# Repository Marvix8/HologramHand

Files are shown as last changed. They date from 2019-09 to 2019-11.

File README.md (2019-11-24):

# Sistemas Operativos Avanzados

## Grupo: &nbsp;X1
- Amengual, Miguel Angel &nbsp;&nbsp;&nbsp;&nbsp;&nbsp; 35991055
- Castagna, Cristian Damian &nbsp;&nbsp;&nbsp;&nbsp;&nbsp; 37398696
- Krause, Ezequiel Otto &nbsp;&nbsp;&nbsp;&nbsp;&nbsp; 39758862
- Scarpello, Franco Dario &nbsp;&nbsp;&nbsp;&nbsp;&nbsp; 37842567

## Proyecto: &nbsp;HologramHand
El fin es crear una experiencia salida de pelicula, al poder **controlar hologramas con gestos de la mano.**

Para poder vivir la experiencia se necesita del guante que estamos desarrollando, siendo este un periférico (mouse, joystick) para celulares, un celular con Android y una sencilla pirámide de acrílico.

Pasos: 
-colocar guante y conectar al celular
-abrir aplicación
-colocar piramide de forma invertida sobre la pantalla con el dispositivo reposado.

**Se recomienda poca luz ambiente*

Y listo, ahora tendrás que comenzar a realizar gesto intuitivos con la mano para por ejmplo pasar de holograma a holograma, achicarlos, agrandarlos y darle a "play" en caso de tener movimiento.

## Descripción detallada del sistema y diseño incremental (Embebido)

### Arduino Uno
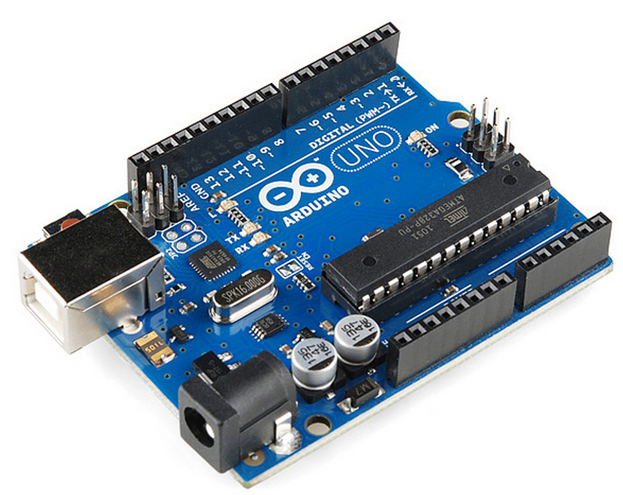
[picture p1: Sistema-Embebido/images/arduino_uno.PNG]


El hardware de Arduino consiste en una placa con un microcontrolador generalmente Atmel con puertos de comunicación y puertos de entrada/salida.

Arduino Uno es una placa electrónica basada en el microcontrolador ATMega 328. Cuenta con 14 entradas/salidas digitales, de las cuales 6 se pueden utilizar como salidas PWM(modulación por ancho de pulsos) y otras 6 son entradas analógicas.

### Bluetooth HC-06
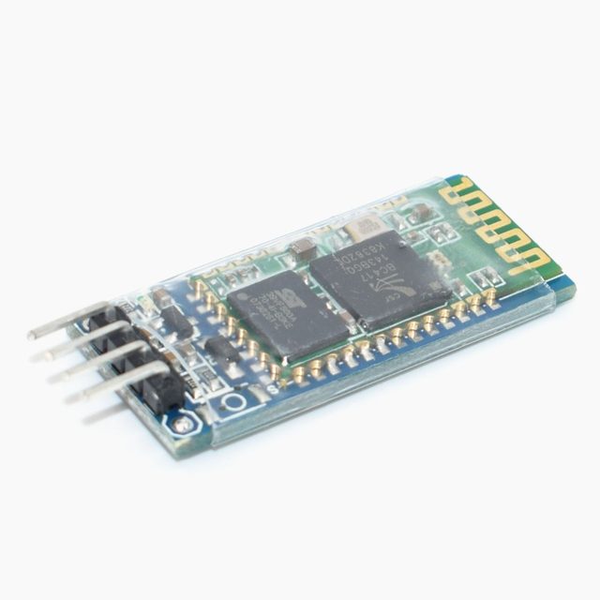
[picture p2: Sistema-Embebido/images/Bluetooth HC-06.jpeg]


El módulo de bluetooth HC-06 es un módulo esclavo, quiere decir que puede recibir conexiones desde un celular, PC, Tablet, pero no es capaz de generar conexiones hacia otros dispositivos bluetooth.

Tiene un modo de comandos AT que debe activarse. Una vez que estamos en el modo de comandos AT, podemos configurar el módulo bluetooth y cambiar parámetros como el nombre del dispositivo, contraseña, entre otras. 

Las conexiones para realizar con Arduino son bastante sencillas. Solamente requerimos colocar como mínimo la alimentación y conectar los pines de transmisión y recepción serial (TX y RX). Hay que recordar que en este caso los pines se deben conectar TX Bluetooth -> TX de Arduino y RX Bluetooth -> RX de Arduino.

### MPU-9250 (Acelerómetro).
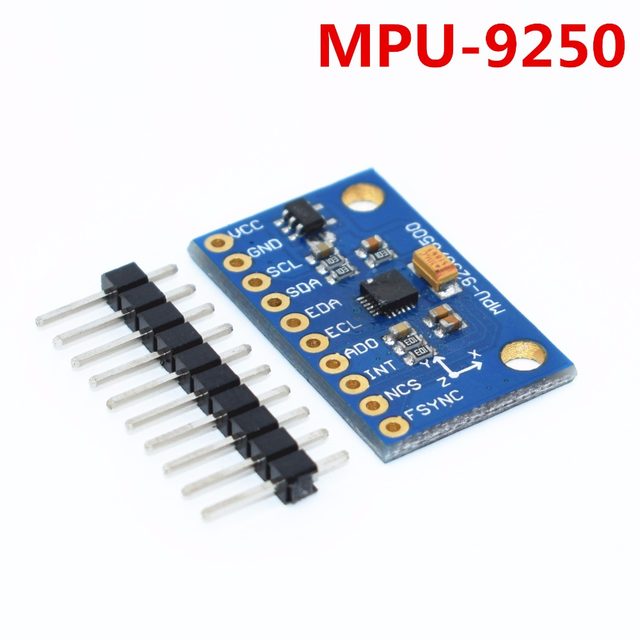
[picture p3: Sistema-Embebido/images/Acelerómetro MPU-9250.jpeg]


Este módulo está basado en el sensor MPU9250 y contiene todo lo necesario para realizar rastreo de movimiento de 9 ejes (9 DoF). Combina un giroscopio de 3 ejes, un acelerómetro de 3 ejes y un magnetómetro de 3 ejes en un mismo chip. Integra un DMP (Procesador digital de movimiento) capaz de realizar complejos algoritmos de captura de movimiento de 9 ejes.

Se comunica con microcontroladores a través de una interfaz I2C y posee una librería muy difundida para su uso inmediato. Este sensor puede entregar 9 grados de libertad e incorpora un regulador de tensión a 3.3V y resistencias pull-up para su uso directo por I2C.

Para una captura precisa de movimiento rápido y lento, posee un rango de escala programable de 250/500/1000/2000 grados/seg para el giroscopio, 2g/4g/8g/16g para el acelerómetro y ±4800µT para el magnetómetro.

### Flex
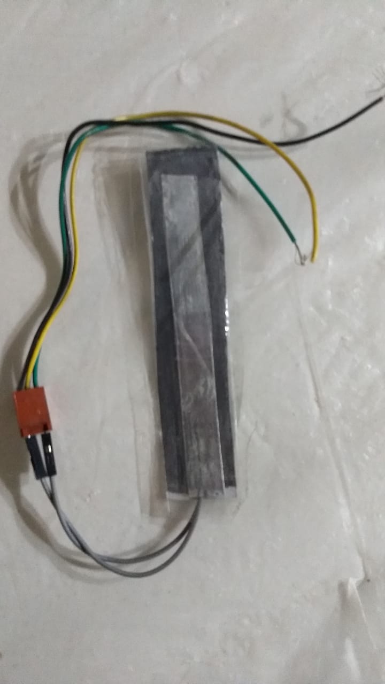
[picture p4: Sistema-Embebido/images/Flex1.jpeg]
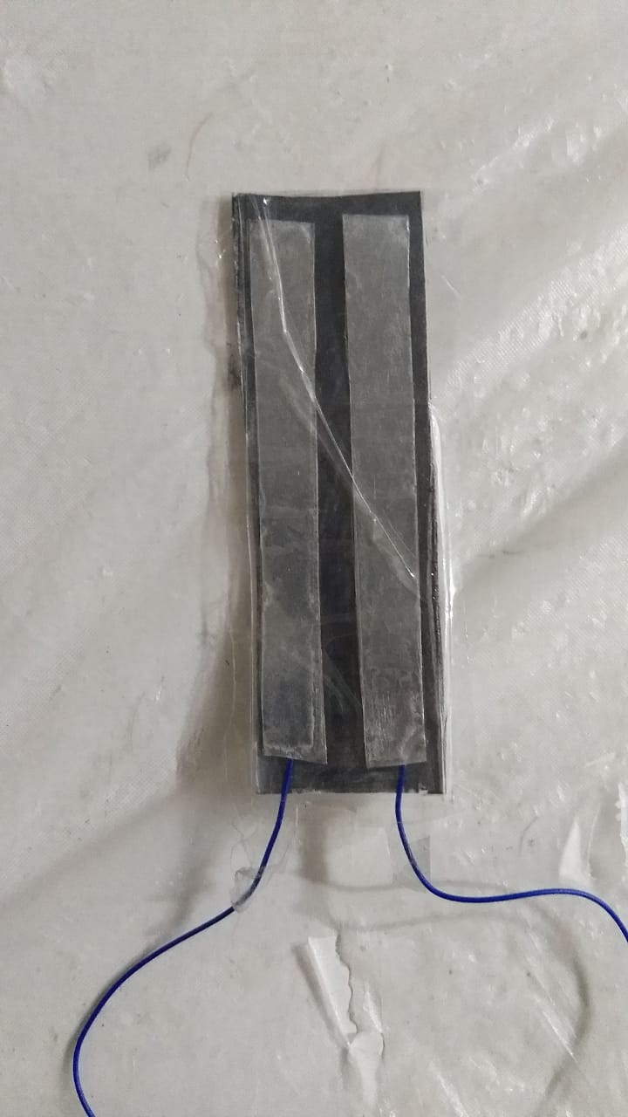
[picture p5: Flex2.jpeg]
  

Este sensor aumenta su resistencia al ser flexionado. El conector tiene dos cables para conectarse directamente al protoboard.
Las dimensiones son 10 cm. x 3 cm. aunque la parte útil que medirá la resistencia doblado es de 8 cm.

### Led Digital
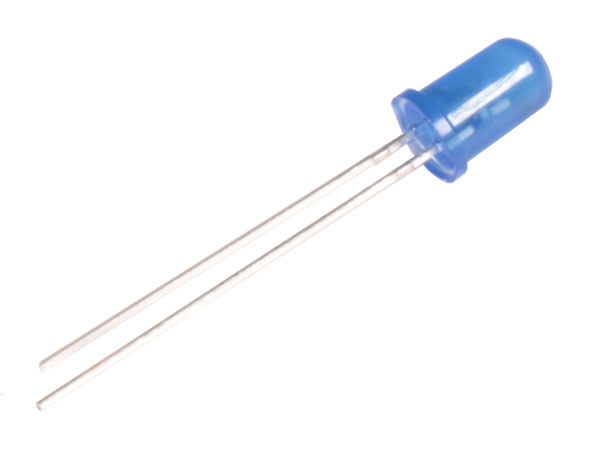
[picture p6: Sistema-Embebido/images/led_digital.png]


Los LEDs de 5mm se presentan encapsulados en una cúpula de resina de color que tiene dos patas. La pata más larga es la de polaridad negativa y se denomina ánodo, la más corta es de polaridad positiva.

-	Color: Azul (455-465nm)
-	Ángulo de apertura: 120 grados
-	Diámetro: 5mm
-	Intensidad lumínica: 4000-5000 mcd
-	Tensión de entrada: 3 V-3,2 V
-	Corriente: 20 mA

### Led Analógico RGB
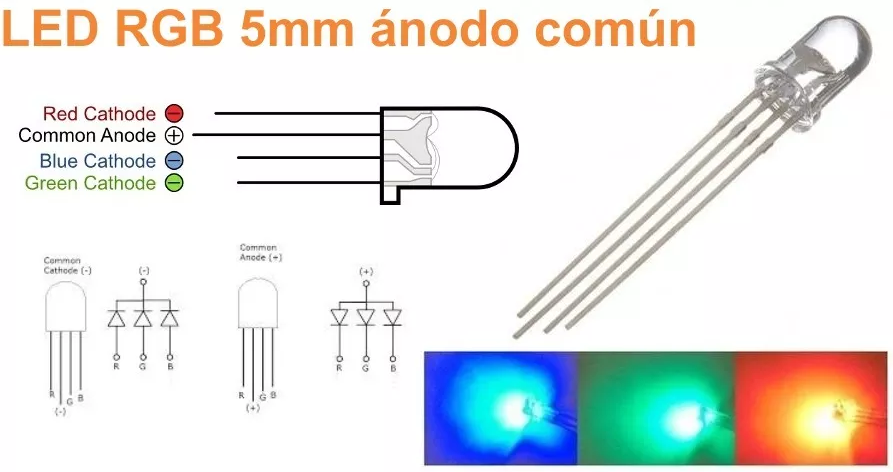
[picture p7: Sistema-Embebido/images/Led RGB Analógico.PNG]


Los LEDs de 5mm se presentan encapsulados en una cúpula de resina de color transparente que tiene cuatro patas: la más larga es de polaridad negativa y se denomina ánodo, las más cortas son de polaridad positiva y se denominan cátodo, en este caso representan el cátodo de R, G y B. Mediante estas patas se indicará la forma en la que el LED debe ser conectado al circuito.

-	Color: RGB
-	Ángulo de apertura: 30 grados
-	Diámetro: 5 mm
-	Longitud de onda: R:625 - G:525 - B:465 nM
-	Tensión de entrada: R:2,1 - G:3,1 - B:3,1 V
-	Intensidad lumínica R:2000 - G:4000 - B:2000 mcd
-	Dimerizable

### Diagrama Físico

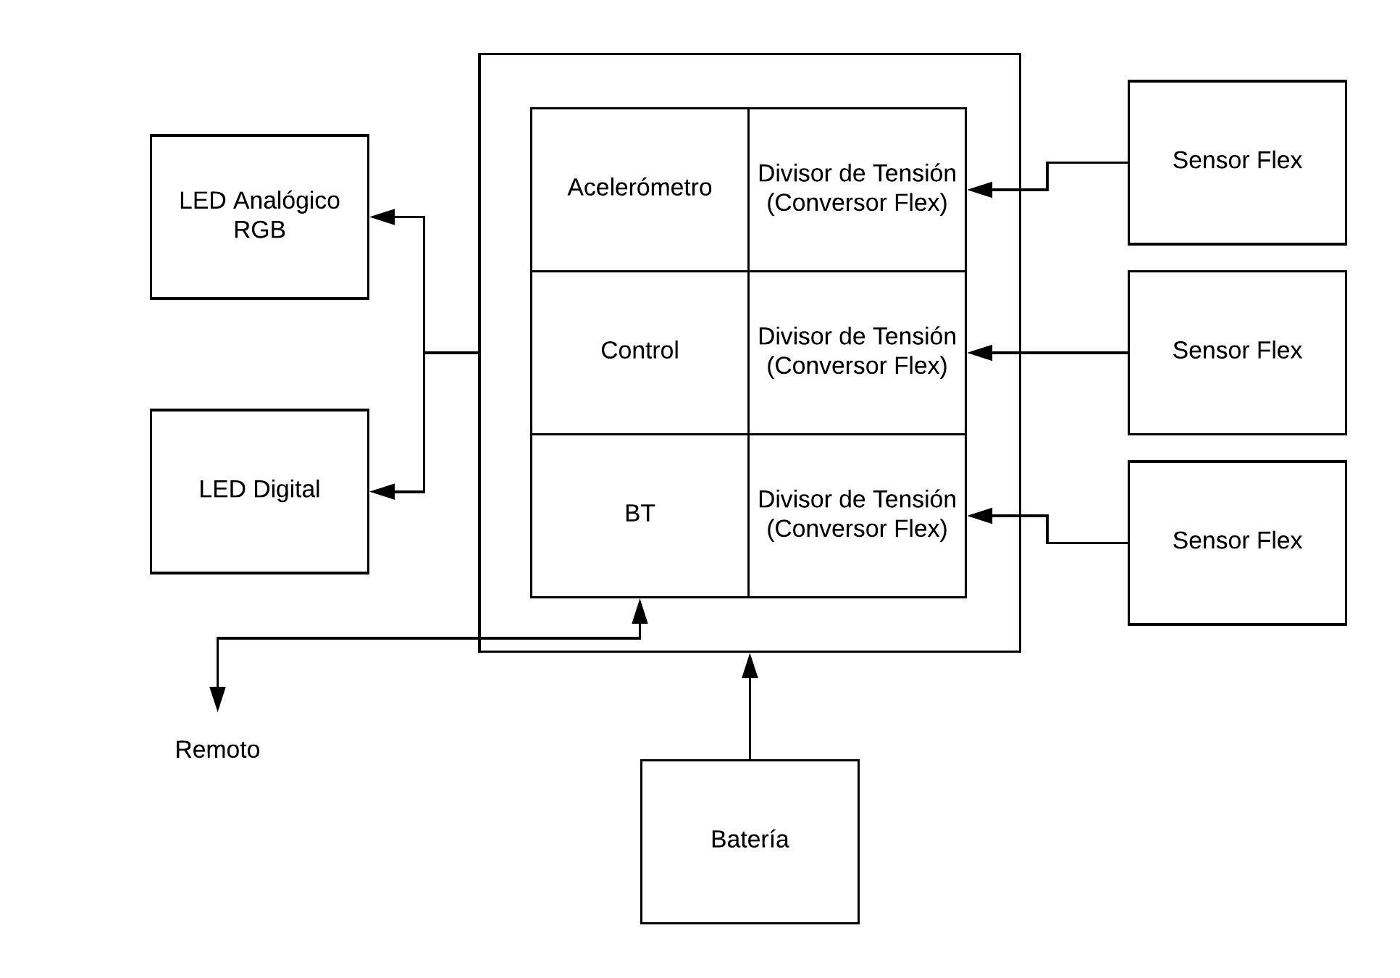
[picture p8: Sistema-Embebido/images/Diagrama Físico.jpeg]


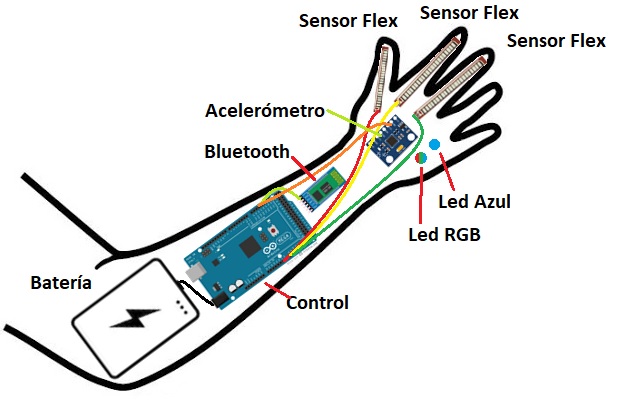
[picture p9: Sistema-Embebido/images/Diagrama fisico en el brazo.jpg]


### Diagrama Lógico

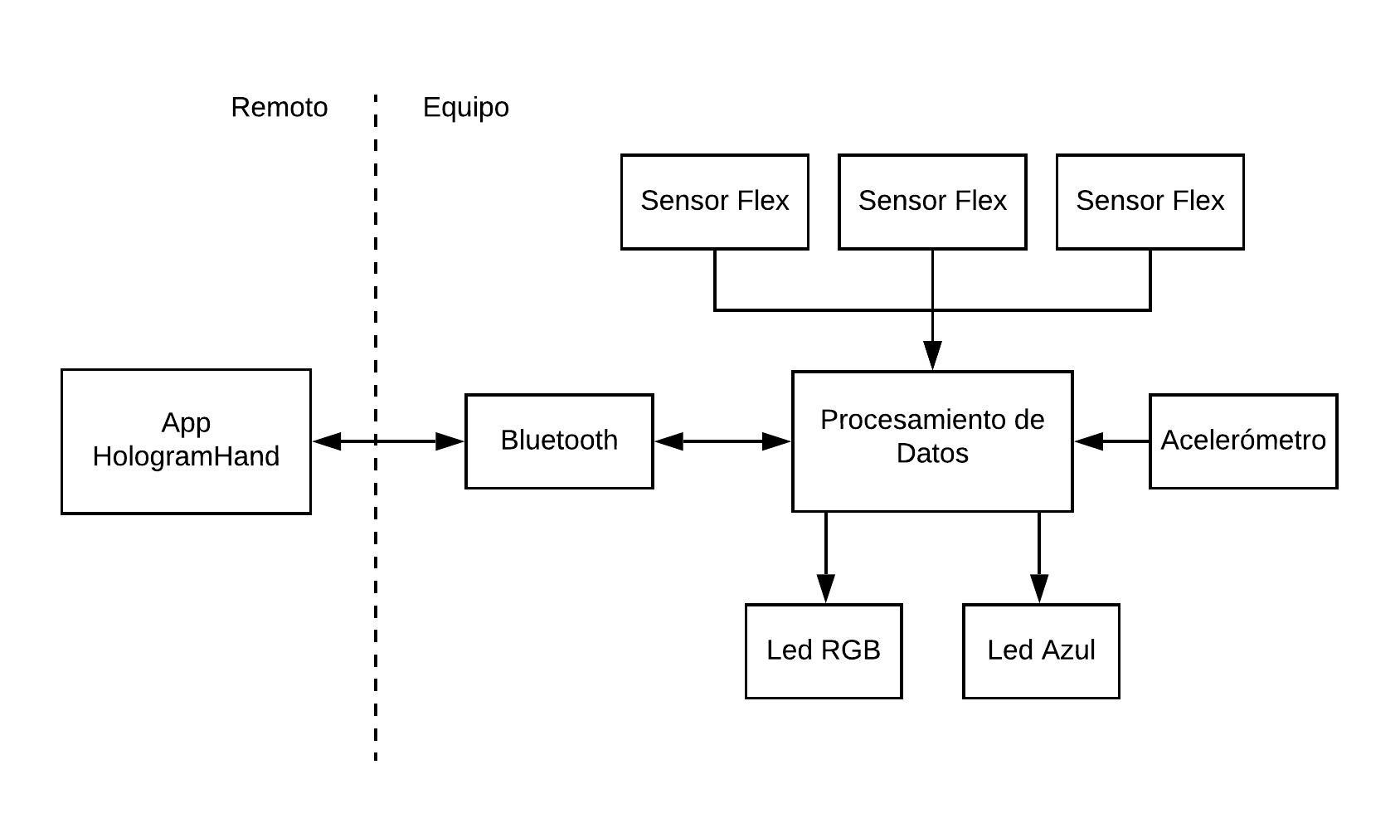
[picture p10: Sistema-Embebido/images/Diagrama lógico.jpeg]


### Diagrama Funcional

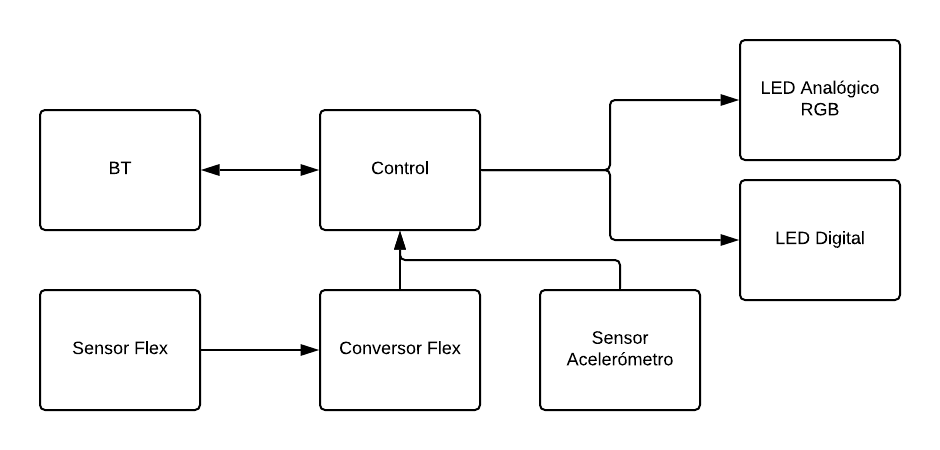
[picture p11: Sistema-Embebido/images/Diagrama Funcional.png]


### Diagrama Circuital

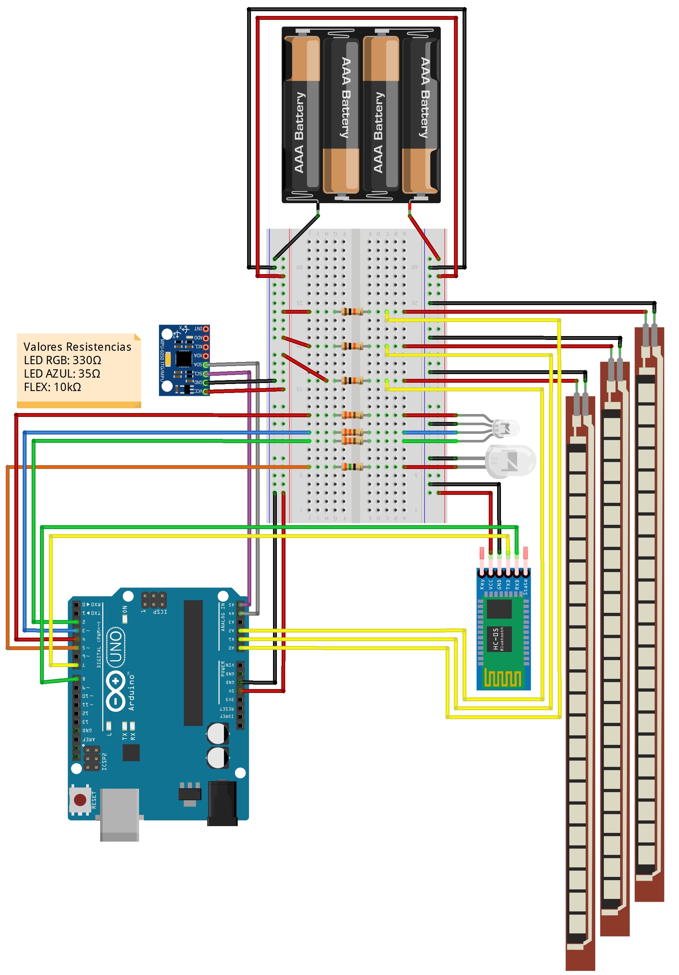
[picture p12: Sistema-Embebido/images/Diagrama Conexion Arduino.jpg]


### Diagrama de Software

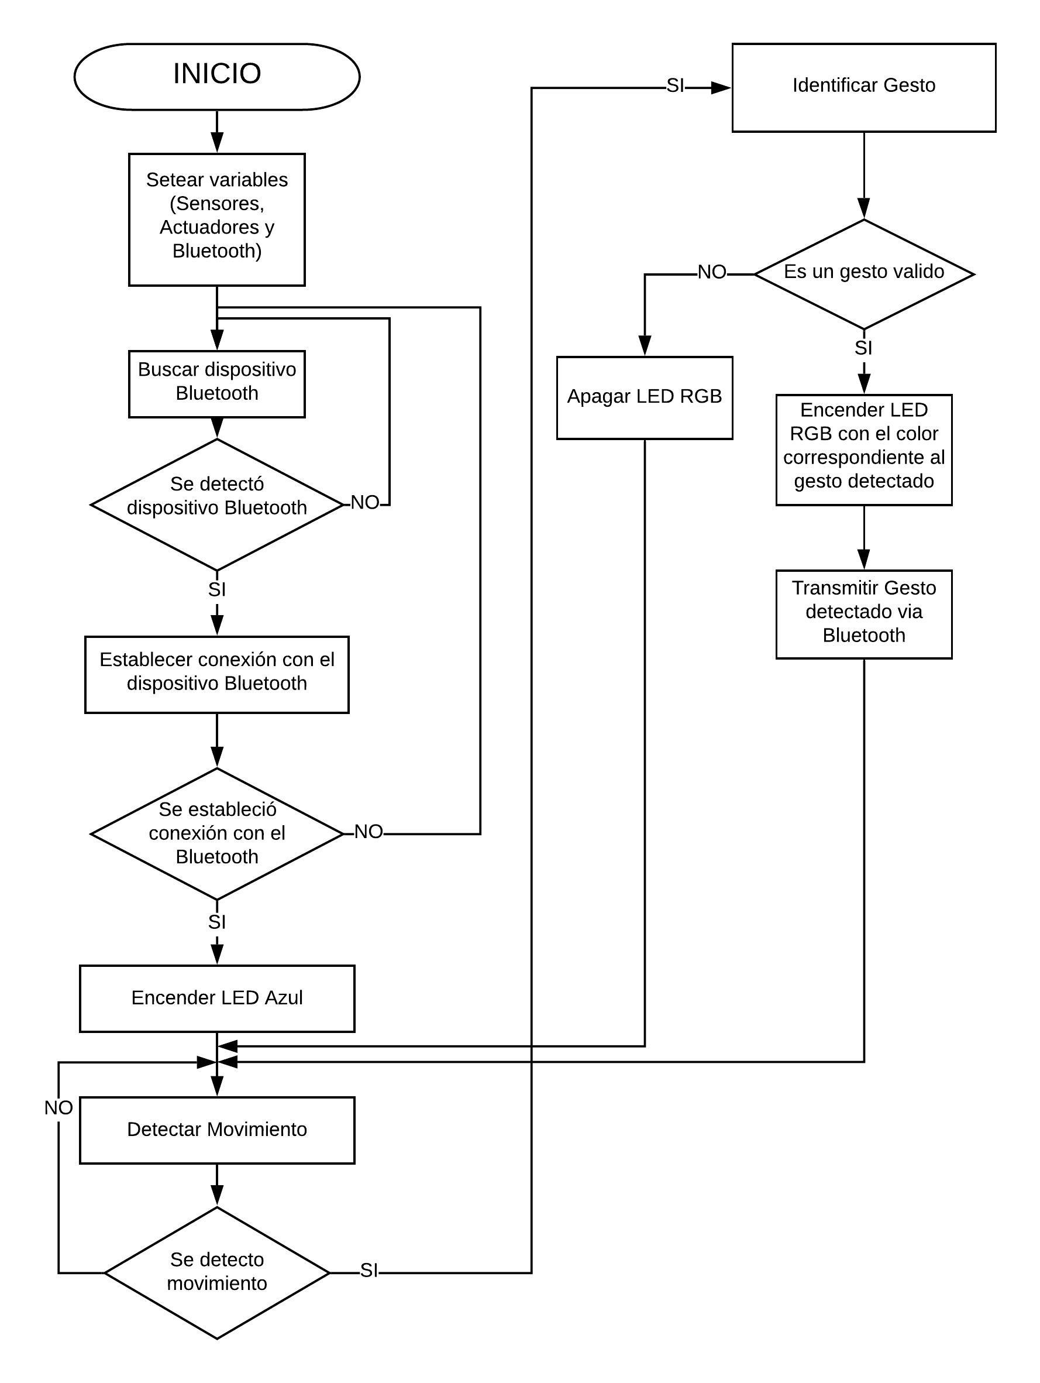
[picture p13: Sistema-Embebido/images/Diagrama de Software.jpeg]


### Armado de sensor Flex
Se hicieron pruebas con los distintos materiales (papel y grafito). Se cortaron pedazos de 110 mm. x 25 mm. de papel de dibujo artístico (de muy bajo gramaje), papel de hoja de impresión (gramaje intermedio) y en hoja canson (gramaje alto). 
Se pintó con un lápiz 9B, a mayor cantidad de B, mayor cantidad de grafito posee, y la mina más blanda es.
Se realizaron mediciones con el multímetro sobre los distintos pedazos de papel:
*  realizando el trazo del lápiz de forma vertical y horizontal, se descartó el trazo de forma horizontal dado que presentaba mayor variación de resistencias. 
* se descartó el que estaba hecho con hoja de impresora puesto que presentaba resistencia muy alta.

Se plantearon dos formas de disponer el conductor de cobre de 100 mm. x 5mm.:
* con dos tiras, una del lado de adelante y otra por detrás de la hoja.
* con dos tiras, ambas de un mismo lado de la hoja.

Se plantearon dos materiales distintos como aislante, plástico de radiografía y plástico de carpeta.

El armado de cada uno de los sensores mencionados se realiza siguiendo los siguientes pasos:

 1. Cortar el papel con tamaño 110 mm. x 25 mm.
 2. Cortar las dos tiras de conductor con tamaño 100 mm. x 5 mm.
 3. Cortar dos cables.
 4. Cortar dos pedazos de aislante (plástico) con tamaño 115 mm. x 25 mm.
 5. Soldar un cable por cada tira de conductor a uno de los extremos del mismo.
 6. Dependiendo del tipo de distribución de las tiras de conductor.
    - En la misma cara
      - Pintar solo una cara del papel con grafito.
      - Pegar con pegamento las dos tiras de conductor sobre uno de los aislantes en la misma cara.
      - Pegar con pegamento la lámina de papel sobre el otro aislante, quedando el grafito del lado opuesto al mismo.
      - Enfrentar ambas caras (conductores contra papel) y unir con cinta adhesiva.
    - En distintas caras.
      - Pintar ambas caras del papel con grafito.
      - Pegar con pegamento cada una de las tiras de conductor sobre cada una de las láminas de aislante.
      - Colocar el papel entre medio de los dos aislantes (los conductores deben quedar presionando sobre el papel).
      - Unir con cinta adhesiva.

#### Armado en imágenes
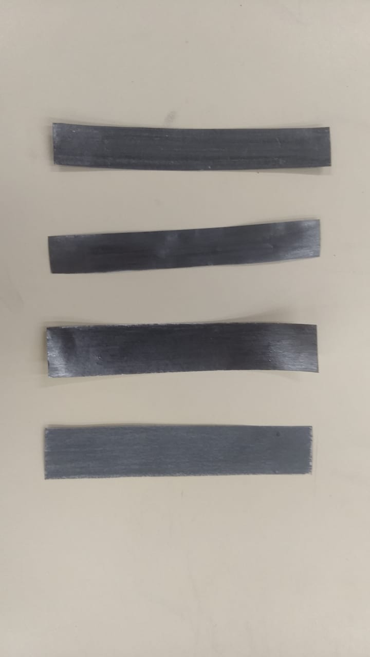
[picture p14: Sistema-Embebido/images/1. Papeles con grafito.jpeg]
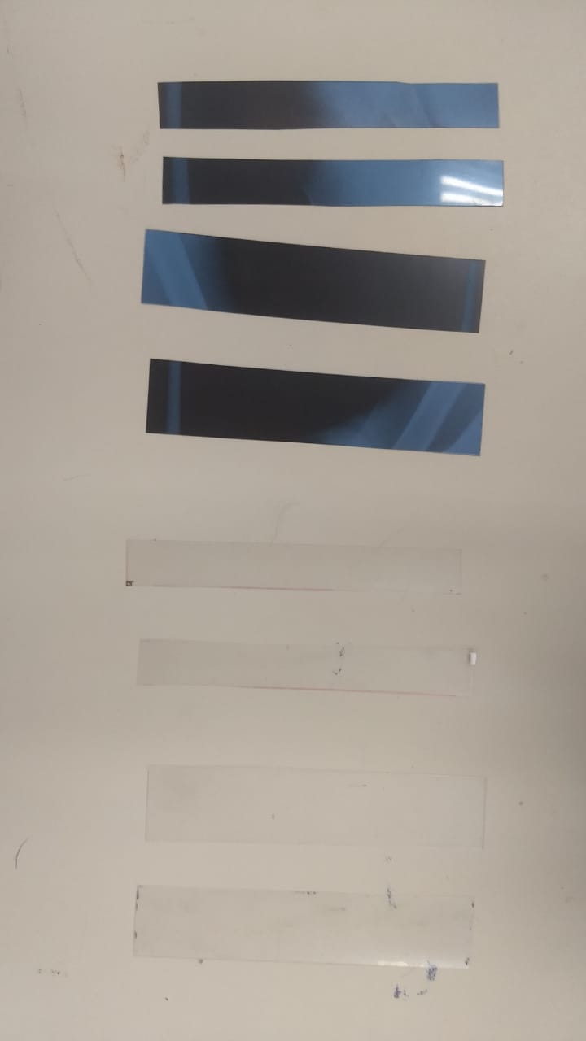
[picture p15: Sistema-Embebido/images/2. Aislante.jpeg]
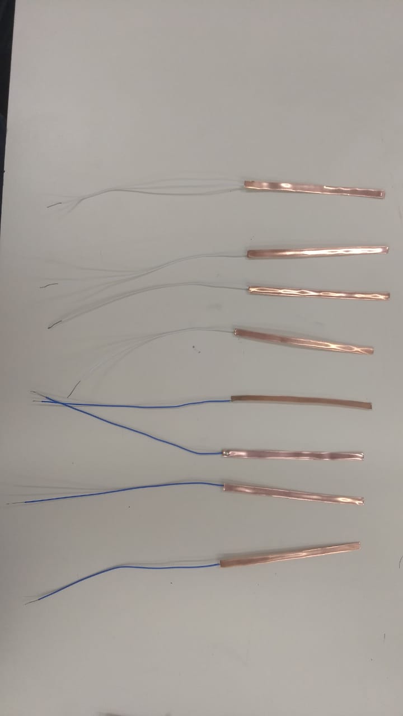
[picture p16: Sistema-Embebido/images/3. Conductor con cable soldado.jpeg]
  

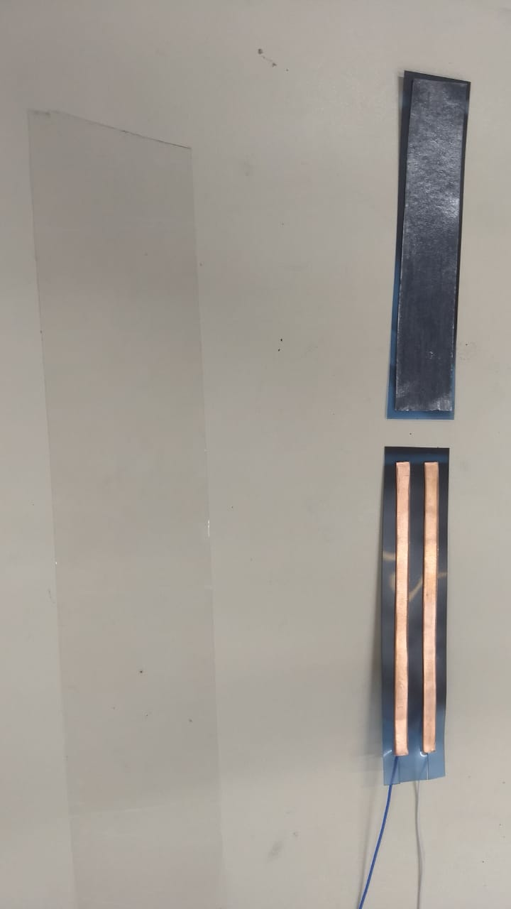
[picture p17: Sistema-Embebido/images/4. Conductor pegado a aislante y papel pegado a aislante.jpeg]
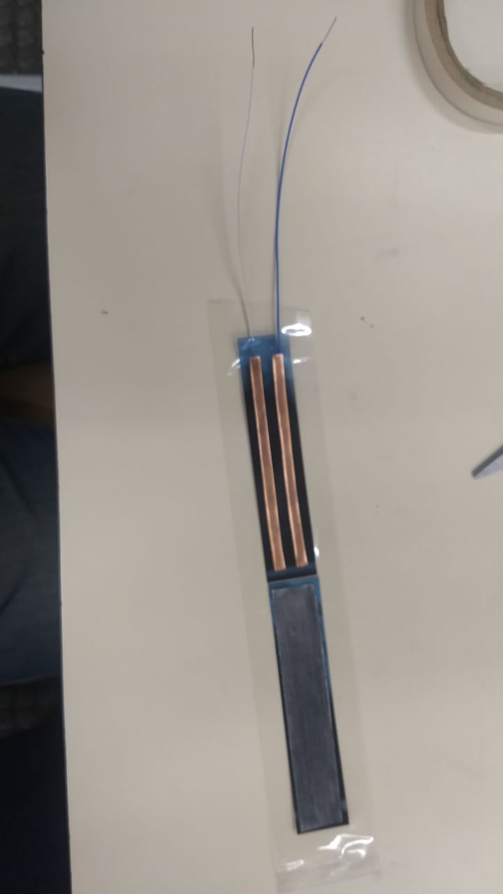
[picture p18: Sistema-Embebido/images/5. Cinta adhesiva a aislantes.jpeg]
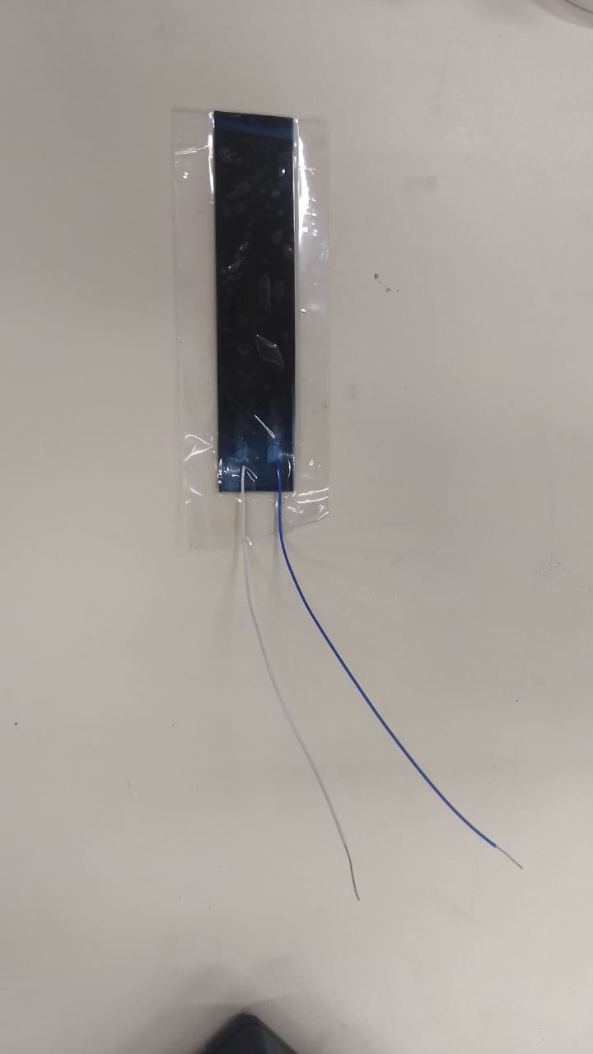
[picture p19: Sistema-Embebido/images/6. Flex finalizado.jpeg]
  

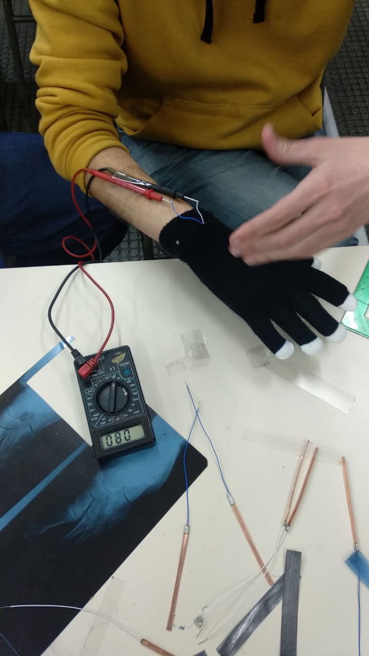
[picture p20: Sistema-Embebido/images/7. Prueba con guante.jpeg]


#### Prototipos
##### Prototipo 1: Ambos conductores en un mismo aislante de plástico de radiografía con papel de dibujo artístico
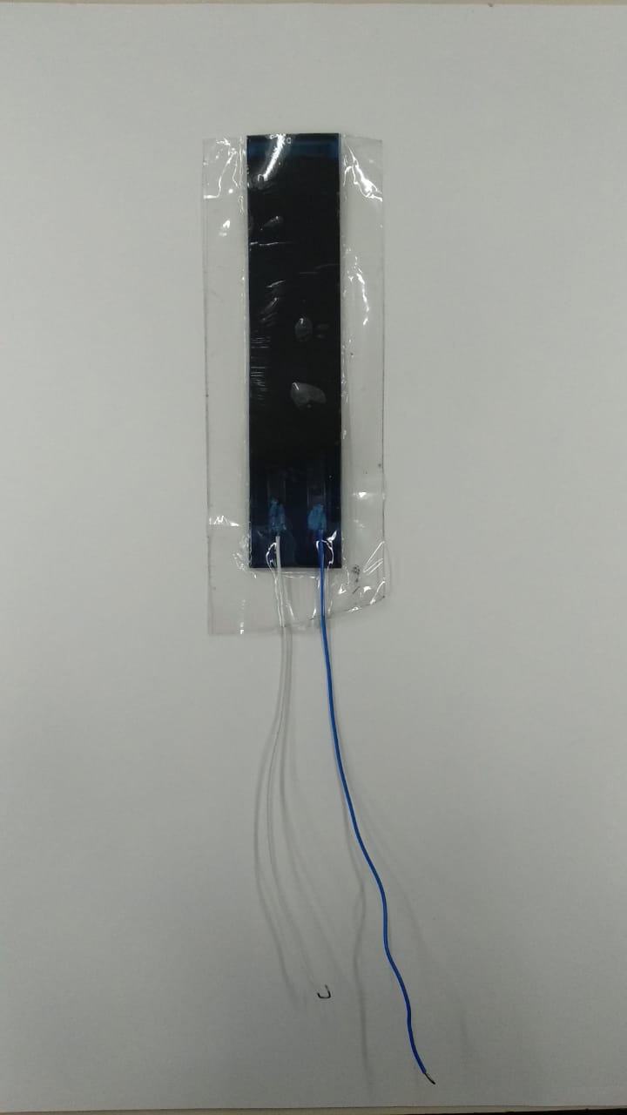
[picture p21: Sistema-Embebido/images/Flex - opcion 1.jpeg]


##### Prototipo 2: Un conductor en cada aislante de plástico de radiografía con papel canson
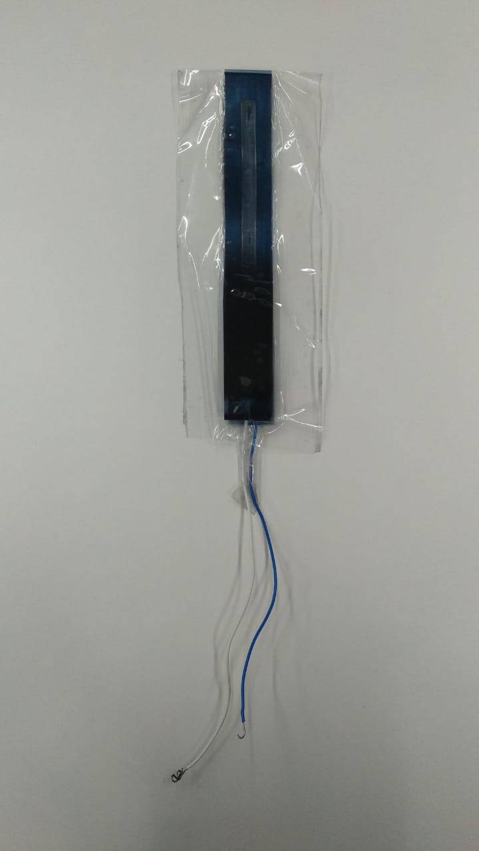
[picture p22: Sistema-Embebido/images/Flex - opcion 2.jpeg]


##### Prototipo 3: Un conductor en cada aislante de plástico de carpeta con papel canson
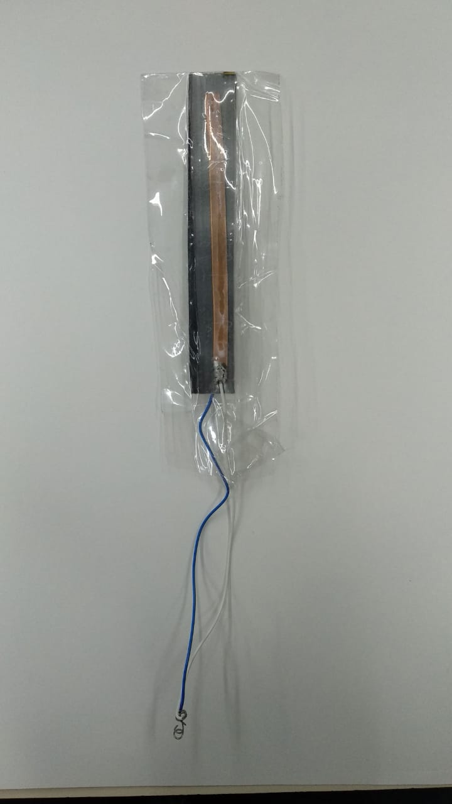
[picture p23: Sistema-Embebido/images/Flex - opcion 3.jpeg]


##### Prototipo 4: Ambos conductores en un mismo aislante de plástico de carpeta con papel de dibujo artístico
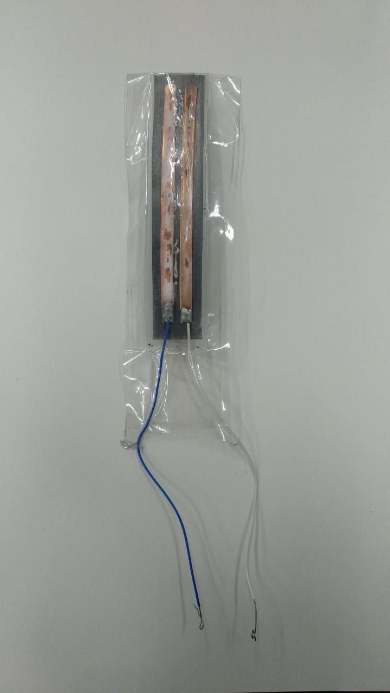
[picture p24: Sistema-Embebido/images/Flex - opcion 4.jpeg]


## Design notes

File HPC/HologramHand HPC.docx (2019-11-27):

HologramHand seguimiento de lesiones

Amengual Miguel Angel, Castagna Cristian Damian, Krause Ezequiel Otto, Scarpello Franco Dario

Universidad Nacional de La Matanza,

Departamento de Ingeniería e Investigaciones Tecnológicas,

Florencio Varela 1903 - San Justo, Argentina

amengualma6@gmail.com, cristiancastagna_1993@hotmail.com, ezeqkr@gmail.com, scarpello.franco@gmail.com

Resumen. En el presente documento se desarrolla la funcionalidad de detección de daño motriz a emplear en el proyecto HologramHand. Para esto se empleará un modelo de procesamiento basado en MPI en donde se genera una red conformada por todas las HologramHand que se encuentren en el mercado. A mayor cantidad de HologramHand disponibles, mayor será el poder de procesamiento conjunto, necesario para resolver la evaluación de daño en la mano del paciente dentro de una única HologramHand. Se pretende con el mecanismo descrito, ahorrar en los costos debidos a soluciones basadas en adquirir nuevo hardware, aprovechando los tiempos ociosos de los procesadores que ya están disponibles por el simple hecho de haber adquirido una unidad de HologramHand.

Palabras claves: HologramHand, HPC, MPI.

1. Introducción

HologramHand es un proyecto basado en la manipulación de hologramas a partir de gestos realizados con la mano. Para cumplir su objetivo principal, cuenta con sensores qué cumplen la función de medir la curvatura de los dedos y un acelerómetro. En este documento ahondaremos en la capacidad de evaluar la recuperación de la mano de un usuario que allá sufrido una lesión en esta.

Generar esta evaluación será una característica que aporta un valor agregado. Sin embargo, es algo complejo que requiere de un poder de procesamiento mayor al que puede tener un único Arduino
R1. Para ofrecer esta funcionalidad comenzaremos explicando cómo se obtendrán las mediciones del movimiento en los dedos del paciente, luego explicaremos como sera procesada la información, y por ultimo como podrá esto ayudar al usuario.

2. Desarrollo

Obtención de la medición

Los movimientos que realizan los dedos de la mano de una persona que se encuentra utilizando el dispositivo(HologramHand), son capturados por los sensores flex, uno por cada dedo de la mano, los cuales convierten la curvatura de su flexión en valores de resistencia eléctrica.

El sistema embebido implementará el filtro de Kalman[1], el cual nos servirá para poder obtener mediciones más limpias de los sensores flex. El filtro de Kalman es un algoritmo recursivo y utiliza un modelo predictivo y correctivo.

Procesamiento de los valores obtenidos

Para conseguir el poder necesario, se utilizará un sistema de comunicación punto a punto[2], en donde cada nodo conectado a la red estará conformado por un dispositivo HologramHand. El nodo que realice la solicitud de procesamiento al resto de los nodos mediante mensajes MPI (de ahora en adelante “nodo maestro”) recibirá como respuesta la cantidad de sensores que puede procesar de cada nodo que responda la solicitud (desde ahora “nodos esclavos”).

El nodo maestro informa a los nodos esclavos los registros de su memoria interna a la cual deben acceder para leer los valores obtenidos por los sensores flex. Por defecto solo se solicitará a los nodos esclavos que procesen la información de un único sensor flex.

Una vez que los valores son leídos por los nodos esclavos, estos generarán una porción del informe del estado de la mano.

Luego de que el nodo receptor haya arme el informe, el mismo es devuelto al nodo maestro.

Interpretación de los valores procesados

El nodo maestro recibe de los nodos esclavos las porciones de informe del estado de la mano, será su trabajo unificar los informes recibidos y presentarlos al usuario de HolgramHand.

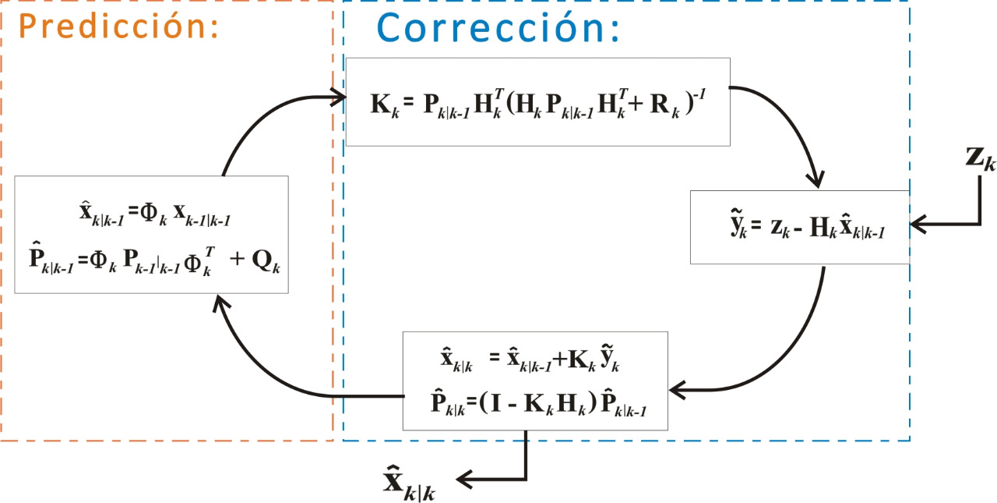
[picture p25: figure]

3. Explicación del algoritmo

Al recibir el anuncio desde la aplicación de crear una evaluación de seguimiento de la recuperación de la mano, este HologramHand pasara a ser el nodo Maestro, entonces se dispara la ejecución del siguiente algoritmo[3].

NODO MAESTRO realizarSolicitudEvaluacion(); socilitarProcesamientoExterno(); indicarRegistrosDeMemoria(); unirInputsDeInforme(); enviarInforme(); | NODO ESCLAVO MPI_INIT(); escucharSolicitudesProcesamiento(); responderPosibilidadDeProcesar(); leerRegistrosDeMemoria(); generarInputDeInforme(); responderInputDeInforme (); MPI_Finalize();

4. Pruebas que pueden realizarse

Una de las pruebas que pueden realizarse es implementar el algoritmo con y sin el empleo de MPI, para así demostrar de forma certera la diferencia en los tiempos de ejecución entre una y otra.

Para poder llevar a cabo la propuesta debe haber en el mercado suficientes unidades de HologramHand como poder de procesamiento sea necesario, a mayor cantidad mayor poder de procesamiento. Cuando el usuario solicite el informe de la mano, se realizará la solicitud a todos los HologramHand que se encuentren disponibles para que puedan ayudar en el procesamiento de la información.

Finalizado el procesamiento, el usuario podrá visualizar el informe de su mano en un dispositivo móvil que tenga la aplicación de HologramHand instalada. La misma se comunicará vía WiFi con el sistema embebido, el cual brindará el informe para luego ser mostrado en el dispositivo móvil.

4. Conclusiones

El seguimiento de una lesión con los medios actuales se vuelve tedioso e inclusive por esta razón es un proceso que suele ser abandonado por los pacientes. Es por este motivo, que la solución planteada está basada en que los usuarios del HologramHand puedan aprovechar al máximo los recursos que ya disponen, hagan el seguimiento de una forma mucho mas cómoda, y ofrecer una mejora al producto, sin elevar el costo final significativamente.

Como el informe está basado en la información brindada solo por los 5 sensores de los dedos, es lógico que el resultado tenga ciertas limitaciones.

Para finalizar, agregamos, que con las misma lógica pero usando otros sensores se podrían generar distintos tipos de evaluaciones, por ejemplo con el giroscopio se podría evaluar la condición de la muñeca y así generar un informe final aun más completo.

5. Referencias
1. An Elementary Introduction to Kalman Filtering (2019), https://arxiv.org/pdf/1710.04055.pdf
2. Computación de Alto Rendimiento, MPI y PETSc (2016), https://cimec.org.ar/~mstorti/curso-mpi-petsc/slides.pdf
3. Performance study of multithreaded MPI and

OpenMP tasking in a large scientific code (2017),
https://www.researchgate.net/publication/318127376_Performance_Study_of_Multithreaded_MPI_and_OpenMP_Tasking_in_a_Large_Scientific_Code

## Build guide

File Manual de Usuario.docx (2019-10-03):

Manual

El control sobre los hologramas se dará de la siguiente manera:

El guante detectara las siguientes 4 posiciones de la mano

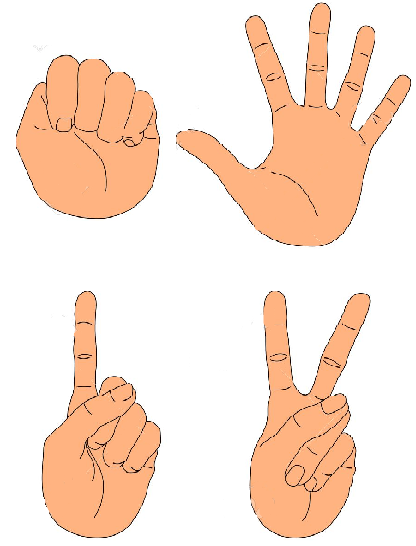
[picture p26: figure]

A partir de la combinación y movimiento entre posiciones determinara los siguientes gestos

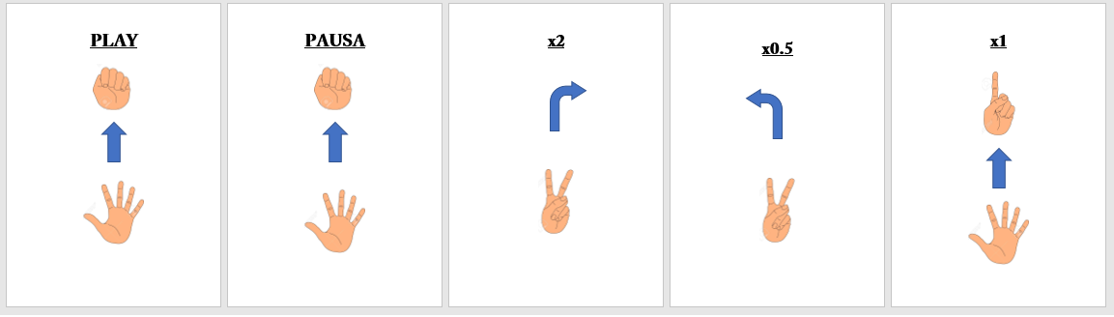
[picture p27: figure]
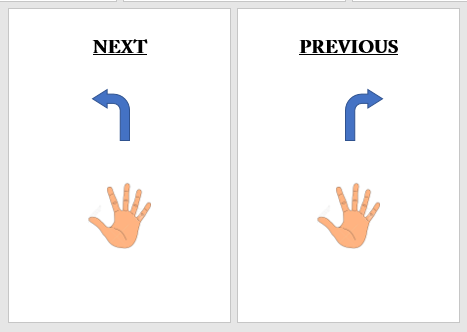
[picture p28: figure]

PLAY:

El holograma actual empezara a moverse.

PAUSE:

El holograma en movimiento se detendra.

x2:

El holograma pasara a moverse al doble de su velocidad original.

x0.5:

El holograma pasara a moverse a la mitad de su velocidad original.

x1:

El holograma retomara su velocidad original en caso de haberla cambiado.

NEXT:

Se pasara a visualizar el siguiente holograma.

PREVIOUS:

Se pasara a visualizar el holograma anterior.

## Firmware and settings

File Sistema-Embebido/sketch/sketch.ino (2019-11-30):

#include "lib/Flex.h"
#include "lib/Hand.h"
#include "lib/Gesture.h"
#include "lib/MPU9250.h"
#include "lib/Kalman.h"
#include <SoftwareSerial.h>    // para la comunicación bluetooth

/*
   Asignación de sensores a los distintos pines del arduino.
*/
#define FLEX_SENSOR_PULGAR  A1
#define FLEX_SENSOR_INDICE  A0
#define FLEX_SENSOR_MEDIO   A2
#define BLUETOOTH_RX        7
#define BLUETOOTH_TX        8
#define BLUE_LED            4
#define RGB_LED_RED         9
#define RGB_LED_BLUE        5
#define RGB_LED_GREEN       6

/*
   Voltaje que reciven los sensores
*/
#define VCC 4.98 // Measured voltage of Ardunio 5V line

/*
   Inputs recibidos desde bluetooth
*/
#define CALIBRATE_STRAIGHT_HAND 83  // S
#define CALIBRATE_BEND_HAND 66      // B
#define TURN_LED 76                 // L

// Valor de la resistencia del divisor de tensión de cada flex.
#define DIVISOR_RESISTANCE_FLEX 100

// Declarar objeto de comunicación bluetooth.
SoftwareSerial bluetooth(BLUETOOTH_RX, BLUETOOTH_TX);

// Declarar objetos de sensores
Flex bigFinger((double)DIVISOR_RESISTANCE_FLEX, 0.5);
Flex indexFinger((double)DIVISOR_RESISTANCE_FLEX, 0.8);
Flex middleFinger((double)DIVISOR_RESISTANCE_FLEX, 0.5);

// Objeto de acelerómetros
MPU9250 IMU(Wire, 0x68);
Acelerometer acelerometer;

Hand hand(bigFinger, indexFinger, middleFinger, acelerometer);
Gesture gesture(hand);

// variables para verificar posición de mano
int previousPosition = -1;
int actualPosition = -1;
int counterSamePosition = 0;

// auxiliares para lectura de sensor flex
double bigFingerFlex;
double indexFingerFlex;
double middleFingerFlex;

// auxiliares para kalman
double filteredMeasurementX;
double filteredMeasurementY;
double filteredMeasurementZ;

// lectura de bluetooth
int bluetoothReader;
char bluetoothSender;

// Kalman para acelerometro
Kalman acelerometerXK(0.7, 15, 1023, 0);
Kalman acelerometerYK(0.8, 15, 1023, 0);
Kalman acelerometerZK(0.8, 8, 1023, 0);

// Prototipos de funciones
void sendInformationViaBluetooth (const int);
void rgbColor (int, int, int);
void ledRGB();

/*
   Configuración inicial de pines y comunicación.
*/
void setup()
{
  pinMode(FLEX_SENSOR_PULGAR, INPUT);
  pinMode(FLEX_SENSOR_INDICE, INPUT);
  pinMode(FLEX_SENSOR_MEDIO, INPUT);
  pinMode(BLUE_LED, OUTPUT);
  pinMode(RGB_LED_RED, OUTPUT);
  pinMode(RGB_LED_BLUE, OUTPUT);
  pinMode(RGB_LED_GREEN, OUTPUT);


  Serial.begin(9600); // Inicializa comunicación en serie.
  bluetooth.begin(9600); // Inicializa comunicación bluetooth.

  IMU.begin();
  IMU.setAccelRange(MPU9250::ACCEL_RANGE_8G);
}

/*
   Sentencias a ejecutar constantemente en el arduino.
*/
void loop()
{
  if (bluetooth.available()) {
    bluetoothReader = bluetooth.read();

    if (bluetoothReader == CALIBRATE_BEND_HAND) {
      hand.calibrateBendHand((double)analogRead(FLEX_SENSOR_PULGAR), (double)analogRead(FLEX_SENSOR_INDICE), (double)analogRead(FLEX_SENSOR_MEDIO));
    }

    if (bluetoothReader == CALIBRATE_STRAIGHT_HAND) {
      hand.calibrateStraightHand((double)analogRead(FLEX_SENSOR_PULGAR), (double)analogRead(FLEX_SENSOR_INDICE), (double)analogRead(FLEX_SENSOR_MEDIO));
      hand.setCalibrated(true);
    }

    if (bluetoothReader == TURN_LED) {
      if (digitalRead(BLUE_LED) == LOW) {
        digitalWrite(BLUE_LED , HIGH);
      } else {
        digitalWrite(BLUE_LED , LOW);
      }
    }
  }

  if (hand.getCalibrated() == true) {
    bigFingerFlex = (double)analogRead(FLEX_SENSOR_PULGAR);
    indexFingerFlex = (double)analogRead(FLEX_SENSOR_INDICE);
    middleFingerFlex = (double)analogRead(FLEX_SENSOR_MEDIO);

    hand.processPosition(bigFingerFlex, indexFingerFlex, middleFingerFlex);

    if (previousPosition == -1) {
      previousPosition = hand.getHandPosition();
    }
    actualPosition = hand.getHandPosition();

    if (actualPosition == previousPosition) {
      counterSamePosition++;
    } else {
      counterSamePosition = 0;
    }
    previousPosition = actualPosition;

    IMU.readSensor();
    filteredMeasurementX = acelerometerXK.getFilteredValue(IMU.getAccelX_mss() * 0.1);
    filteredMeasurementY = acelerometerYK.getFilteredValue(IMU.getAccelY_mss() * (-0.1));
    filteredMeasurementZ = acelerometerZK.getFilteredValue(IMU.getAccelZ_mss() * 0.1);

    if (counterSamePosition == 1500) {
      acelerometer.setAxisValues(filteredMeasurementX, filteredMeasurementY, filteredMeasurementZ);

      hand.process();
      gesture.readInput();
      gesture.updateStateMachine();

      ledRGB();

      if (gesture.getAction() != '9') {
        bluetoothSender = gesture.getAction();
        bluetooth.write(bluetoothSender);
      }
      counterSamePosition = 0;
    }
  }
  else {
    rgbColor(LOW, LOW, LOW);
  }
}

/*
   Función utilizada para seleccionar el color a encender
   del led RGB
*/
void ledRGB() {
  switch (hand.getMovement()) {
    case (int)SPZ: rgbColor(255, 0, 0); break; // rojo
    case (int)SNZ: rgbColor(0, 255, 0); break; // verde
    case (int)SPY: rgbColor(0, 0, 255); break; // azul
    case (int)SPX: rgbColor(255, 255, 255); break; // blanco
    case (int)RPY: rgbColor(255, 255, 0); break; // amarillo
    case (int)RPZ: rgbColor(255, 0, 255); break; // magenta
    case (int)GNZ: rgbColor(0, 255, 255); break; // cyan
    case (int)GPZ: rgbColor(0, 255, 148); break; // violeta
    case (int)GPX: rgbColor(60, 40, 0); break; // naranja
    case (int)SCPY: rgbColor(128, 0, 0); break; // marrón
    case (int)SCNZ: rgbColor(0, 0, 128); break; // navy
    case (int)UNDEFINED: rgbColor(LOW, LOW, LOW); break; // apagado
  }
}


/*
   Función utilizada para cambiar el color de led RGB
   Entrada:
   @redLightValue: cantidad de color rojo.
   @blueLightValue: cantidad de color azul.
   @greenLightValue: cantidad de color verde.
*/
void rgbColor (int redLightValue, int greenLightValue, int blueLightValue)
{
  analogWrite(RGB_LED_RED, redLightValue);
  analogWrite(RGB_LED_BLUE, blueLightValue);
  analogWrite(RGB_LED_GREEN, greenLightValue);
}

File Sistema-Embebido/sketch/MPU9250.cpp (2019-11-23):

/*
MPU9250.cpp
Brian R Taylor
brian.taylor@bolderflight.com

Copyright (c) 2017 Bolder Flight Systems

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
THE SOFTWARE IS PROVIDED "AS IS", WITHOUT WARRANTY OF ANY KIND, EXPRESS OR IMPLIED, INCLUDING 
BUT NOT LIMITED TO THE WARRANTIES OF MERCHANTABILITY, FITNESS FOR A PARTICULAR PURPOSE AND 
NONINFRINGEMENT. IN NO EVENT SHALL THE AUTHORS OR COPYRIGHT HOLDERS BE LIABLE FOR ANY CLAIM, 
DAMAGES OR OTHER LIABILITY, WHETHER IN AN ACTION OF CONTRACT, TORT OR OTHERWISE, ARISING FROM, 
OUT OF OR IN CONNECTION WITH THE SOFTWARE OR THE USE OR OTHER DEALINGS IN THE SOFTWARE.
*/

#include "Arduino.h"
#include "lib/MPU9250.h"

/* MPU9250 object, input the I2C bus and address */
MPU9250::MPU9250(TwoWire &bus,uint8_t address){
  _i2c = &bus; // I2C bus
  _address = address; // I2C address
}

/* starts communication with the MPU-9250 */
int MPU9250::begin(){
  // using I2C for communication
  // starting the I2C bus
  _i2c->begin();
  // setting the I2C clock
  _i2c->setClock(_i2cRate);

  // enable I2C master mode
  if(writeRegister(USER_CTRL,I2C_MST_EN) < 0){
    return -2;
  }
  // set the I2C bus speed to 400 kHz
  if(writeRegister(I2C_MST_CTRL,I2C_MST_CLK) < 0){
    return -3;
  }
  // set AK8963 to Power Down
  writeAK8963Register(AK8963_CNTL1,AK8963_PWR_DOWN);

  // wait for MPU-9250 to come back up
  delay(1);
  // reset the AK8963
  writeAK8963Register(AK8963_CNTL2,AK8963_RESET);

  // check the WHO AM I byte, expected value is 0x71 (decimal 113) or 0x73 (decimal 115)
  if((whoAmI() != 113)&&(whoAmI() != 115)){
    return -5;
  }
  // enable accelerometer and gyro
  if(writeRegister(PWR_MGMNT_2,SEN_ENABLE) < 0){
    return -6;
  }
  // setting accel range to 8G as default
  if(writeRegister(ACCEL_CONFIG,ACCEL_FS_SEL_8G) < 0){
    return -7;
  }
  _accelScale = G * 8.0f/32767.5f; // setting the accel scale to 8G
  _accelRange = ACCEL_RANGE_8G;

  // setting the sample rate divider to 0 as default
  if(writeRegister(SMPDIV,0x00) < 0){ 
    return -11;
  } 

  // enable I2C master mode
  if(writeRegister(USER_CTRL,I2C_MST_EN) < 0){
  	return -12;
  }
	// set the I2C bus speed to 400 kHz
	if( writeRegister(I2C_MST_CTRL,I2C_MST_CLK) < 0){
		return -13;
	}
	// check AK8963 WHO AM I register, expected value is 0x48 (decimal 72)
	if( whoAmIAK8963() != 72 ){
    return -14;
	}
  /* get the magnetometer calibration */
  // set AK8963 to Power Down
  if(writeAK8963Register(AK8963_CNTL1,AK8963_PWR_DOWN) < 0){
    return -15;
  }
  delay(100); // long wait between AK8963 mode changes
  // set AK8963 to FUSE ROM access
  if(writeAK8963Register(AK8963_CNTL1,AK8963_FUSE_ROM) < 0){
    return -16;
  }
  delay(100); // long wait between AK8963 mode changes

  // instruct the MPU9250 to get 7 bytes of data from the AK8963 at the sample rate
  readAK8963Registers(AK8963_HXL,7,_buffer);

  // successful init, return 1
  return 1;
}

/* sets the accelerometer full scale range to values other than default */
int MPU9250::setAccelRange(AccelRange range) {
  // setting the accel range to 8G
  if(writeRegister(ACCEL_CONFIG,ACCEL_FS_SEL_8G) < 0){
    return -1;
  }
  _accelScale = G * 8.0f/32767.5f; // setting the accel scale to 8G
  _accelRange = range;
  return 1;
}


/* reads the most current data from MPU9250 and stores in buffer */
int MPU9250::readSensor() {
  // grab the data from the MPU9250
  if (readRegisters(ACCEL_OUT, 21, _buffer) < 0) {
    return -1;
  }
  // combine into 16 bit values
  _axcounts = (((int16_t)_buffer[0]) << 8) | _buffer[1];  
  _aycounts = (((int16_t)_buffer[2]) << 8) | _buffer[3];
  _azcounts = (((int16_t)_buffer[4]) << 8) | _buffer[5];
  _tcounts = (((int16_t)_buffer[6]) << 8) | _buffer[7];
  // transform and convert to float values
  _ax = (((float)(tX[0]*_axcounts + tX[1]*_aycounts + tX[2]*_azcounts) * _accelScale) - _axb)*_axs;
  _ay = (((float)(tY[0]*_axcounts + tY[1]*_aycounts + tY[2]*_azcounts) * _accelScale) - _ayb)*_ays;
  _az = (((float)(tZ[0]*_axcounts + tZ[1]*_aycounts + tZ[2]*_azcounts) * _accelScale) - _azb)*_azs;
  return 1;
}

/* returns the accelerometer measurement in the x direction, m/s/s */
float MPU9250::getAccelX_mss() {
  return _ax;
}

/* returns the accelerometer measurement in the y direction, m/s/s */
float MPU9250::getAccelY_mss() {
  return _ay;
}

/* returns the accelerometer measurement in the z direction, m/s/s */
float MPU9250::getAccelZ_mss() {
  return _az;
}

/* writes a byte to MPU9250 register given a register address and data */
int MPU9250::writeRegister(uint8_t subAddress, uint8_t data){
  /* write data to device */
  _i2c->beginTransmission(_address); // open the device
  _i2c->write(subAddress); // write the register address
  _i2c->write(data); // write the data
  _i2c->endTransmission();

  delay(10);
  
  /* read back the register */
  readRegisters(subAddress,1,_buffer);
  /* check the read back register against the written register */
  if(_buffer[0] == data) {
    return 1;
  }
  else{
    return -1;
  }
}

/* reads registers from MPU9250 given a starting register address, number of bytes, and a pointer to store data */
int MPU9250::readRegisters(uint8_t subAddress, uint8_t count, uint8_t* dest){
  _i2c->beginTransmission(_address); // open the device
  _i2c->write(subAddress); // specify the starting register address
  _i2c->endTransmission(false);
  _numBytes = _i2c->requestFrom(_address, count); // specify the number of bytes to receive
  if (_numBytes == count) {
    for(uint8_t i = 0; i < count; i++){ 
      dest[i] = _i2c->read();
    }
    return 1;
  } else {
    return -1;
  }
}

/* writes a register to the AK8963 given a register address and data */
int MPU9250::writeAK8963Register(uint8_t subAddress, uint8_t data){
  // set slave 0 to the AK8963 and set for write
	if (writeRegister(I2C_SLV0_ADDR,AK8963_I2C_ADDR) < 0) {
    return -1;
  }
  // set the register to the desired AK8963 sub address 
	if (writeRegister(I2C_SLV0_REG,subAddress) < 0) {
    return -2;
  }
  // store the data for write
	if (writeRegister(I2C_SLV0_DO,data) < 0) {
    return -3;
  }
  // enable I2C and send 1 byte
	if (writeRegister(I2C_SLV0_CTRL,I2C_SLV0_EN | (uint8_t)1) < 0) {
    return -4;
  }
	// read the register and confirm
	if (readAK8963Registers(subAddress,1,_buffer) < 0) {
    return -5;
  }
	if(_buffer[0] == data) {
  	return 1;
  } else{
  	return -6;
  }
}
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

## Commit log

2019-09-04 estructura de carpetas
2019-09-04 agrego resto de las carpetas
2019-09-12 Readme con prototipos de sensor flex
2019-09-12 fix de items
2019-09-22 Se agrega imagen de diagrama circuital arduino
2019-09-22 Se agrega la imagen al Readme
2019-09-22 Se arregla el diagrama fisico
2019-09-22 Correccion en la conexion de la pata del led digital
2019-09-22 Se agrega el diagrama fisico presentado en el brazo
2019-09-22 Se agrega el diagrama de Software
2019-09-28 Primer aproximacion de filtro de Kalman
2019-09-28 codigo incial arduino
2019-09-29 Sensores flex, comunicacion blueetooth, resta Leds y Acelerometro
    [sketch.ino]
2019-09-29 Agregada logica de prendido y apagado de LEDs segun diagrama funcional
2019-10-02 Se agrega la imagen del diagrama lógico.
2019-10-02 Se agrega la imagen al reame.
2019-10-03 Se sube manual de usuario.
2019-10-14 Acerca de nosotros
2019-10-19 Se establece la conexion, falta letura y escritura bluetooth
2019-11-02 cambios en el run
2019-11-02 Se agrega la conexion bluetooth
2019-11-02 Logica flex, gesture, hand, parte de main, resta resolver constructor by ref
    [sketch.ino]
2019-11-02 Intento de reproduccion de video
2019-11-09 funciona la reproduccion de videos
2019-11-15 Se refactoriza el receiver
2019-11-15 Se agrega logica de skipF, skipB, play, pause
2019-11-16 Refactor de codigo Android y pruebas en reproductor de video
2019-11-16 fixes de clases hand y gesture
    [sketch.ino]
2019-11-16 logica principal de arduino
2019-11-16 Sensors working
2019-11-16 Se agrego el shake
2019-11-23 sketch finalizado, resta correccion de bugs
    [sketch.ino]
2019-11-23 Fixes, funcionan las acciones
    [MPU9250.cpp, sketch.ino]
2019-11-23 Terminada la configuracion de la mano
2019-11-23 Ajustes a factor de flex y maq de estado
    [Maquina de estados - Inputs y States.xlsx]
2019-11-24 led digital incorporado
2019-11-24 se agrega logica led rgb
2019-11-24 Arreglado problemas de sensores y se agrega la configuracion de sensor de Luz
2019-11-24 Cmabio en readme, arduino mega por uno
2019-11-24 fix imagne arduino uno
2019-11-24 Fixed de comunicacion arduino-android
    [Maquina de estados - Inputs y States.xlsx]
2019-11-27 arduino finished
2019-11-27 arduino last version
2019-11-27 Se actualizan diagramas
    [HologramHand.fzz]
2019-11-28 Fix sensorManagerException
2019-11-30 last arduino fix
